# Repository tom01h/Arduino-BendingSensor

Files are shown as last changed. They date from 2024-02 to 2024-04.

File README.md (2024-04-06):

# ひずみゲージでスキー板のたわみを測る

[Arduino UNO R4もどきのボードと自作基板](https://github.com/tom01h/RA4M1)を使って実験します

事情あって、センサー部分は実際にスキー場で使っているものですが、制御部分はスキー場で使っているものとは別のものです

センサー部分は[ひずみゲージ](https://ja.aliexpress.com/item/1005003672107724.html)（BX120-100AA）と[HX711](https://ja.aliexpress.com/item/1005004245273524.html)（Mini Board）をちょい変(3.3V化)したものを使います

## Arduinoもどき

制御には[Arduino UNO R4もどきのボードと自作基板](https://github.com/tom01h/RA4M1)を使います

D5端子がクロック、D2,D3,D4端子がデータ入力端子です

プログラムは`BendingSensor.ino`です  
LCDに計測値を表示するためにu8g2ライブラリを使います

1秒に10回計測値を表示、最初の10回はゼロキャリブレーションに使います

### ピン配置
下の絵ではJ5,J9がDATA0(D4)で、絵には無いけどJ10,J11がDATA1(D3)でJ15,J16がDATA2(D2)です  
それぞれ、どちらか一方のコネクタを使います

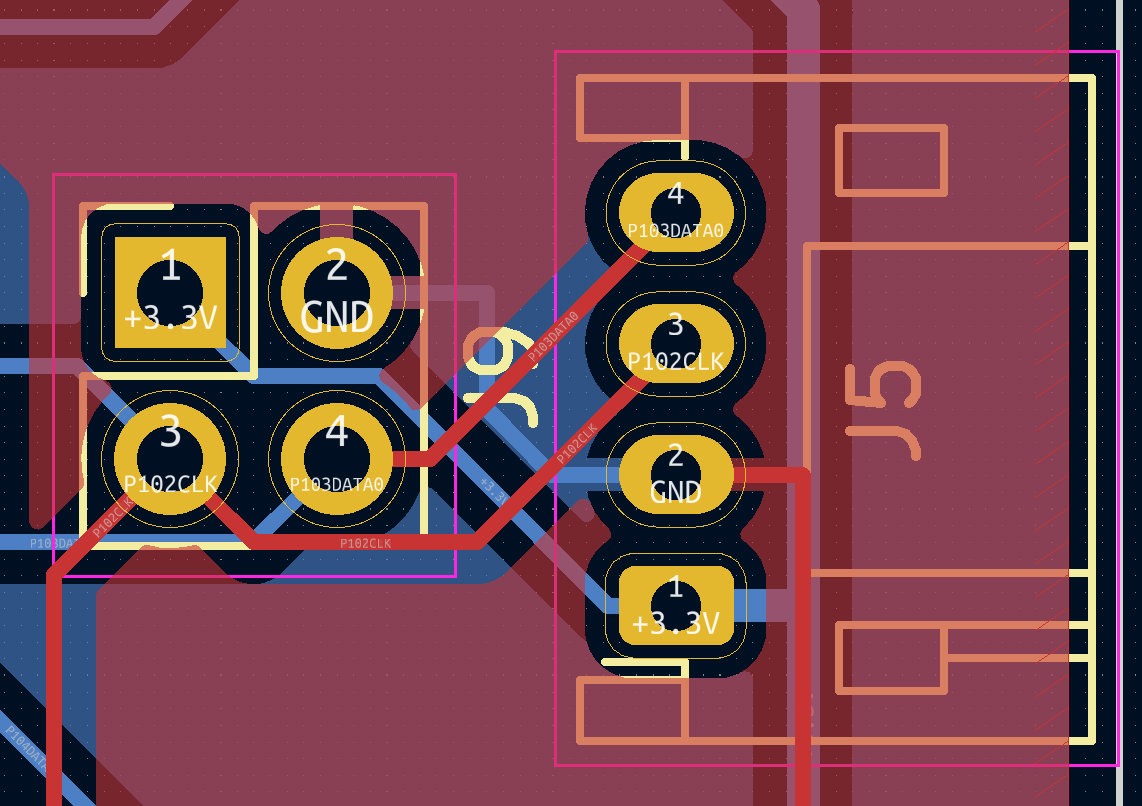
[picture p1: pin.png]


## センサー

### HX711を改造する
3.3Vに対応するために[ここ](https://kohacraft.com/archives/202103201133.html)の真似をして改造します  
(合成抵抗違うくね？って気はしますが…)  
とっても細かい作業です

2個のひずみゲージと組み合わせてホイートストンブリッジを作るための基板が`hx711.kicad_XX`です  
切り取って使います  
0.8mm厚で作りました  
あまり良くないと言われている基板同士のはんだ付け

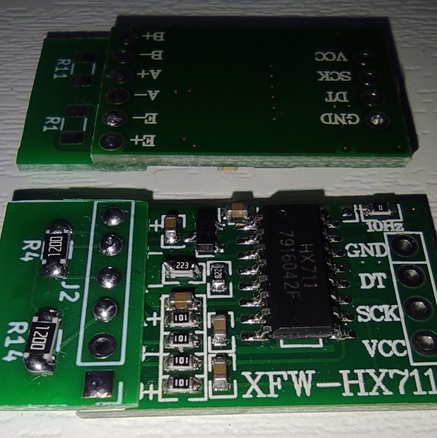
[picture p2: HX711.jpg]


### 回路
(E+)-(A+)間にひずみゲージを表向きに、(E+)-(A-)間にひずみゲージを裏向きに、(A+)-(E-)と(A-)-(E-)間は固定の抵抗(120Ω)をつなぎます  
2枚使っているのは温度補償のため  
スキー板の表裏に貼るわけにもいかないので、間に挟んだ0.4mm厚のプラバンに瞬間接着剤で固定しています  
それ以外の部分は大体でついていればよいので両面テープで固定しています

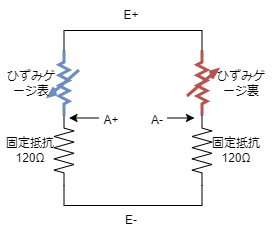
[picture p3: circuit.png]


### 設計図（のようなもの）
断面図

センサー部分は上から
- 100mm x 15mm のプラバン（0.4mm厚）
- 両面テープ
- ひずみゲージ（表）
- 瞬間接着剤
- 100mm x 15mm のプラバン（0.4mm厚）
- 瞬間接着剤
- ひずみゲージ（裏）
- 両面テープ
- 135mm x 15mm のプラバン（0.4mm厚）

HX711をプラバンに止めているのは1.2mm厚の両面テープ



センサー部分の平面図



### 組み立て
古い写真です
#### センサー部分

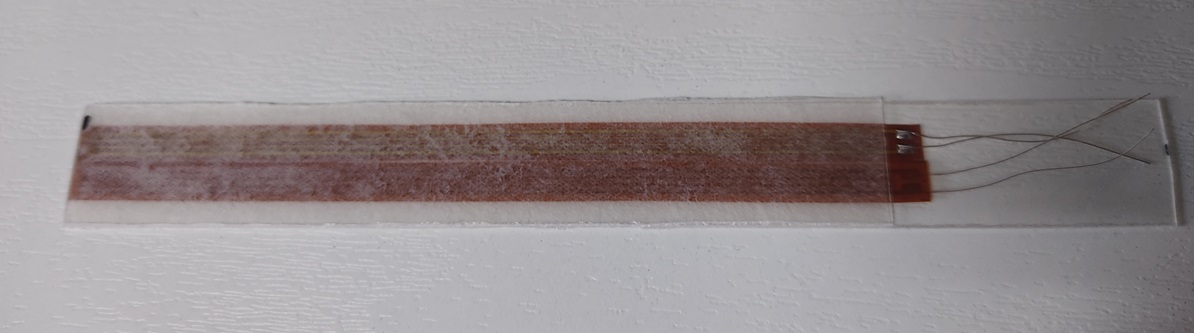
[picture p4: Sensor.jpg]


#### センサーとHX711接続
下の写真はHX711基板は裏返った状態

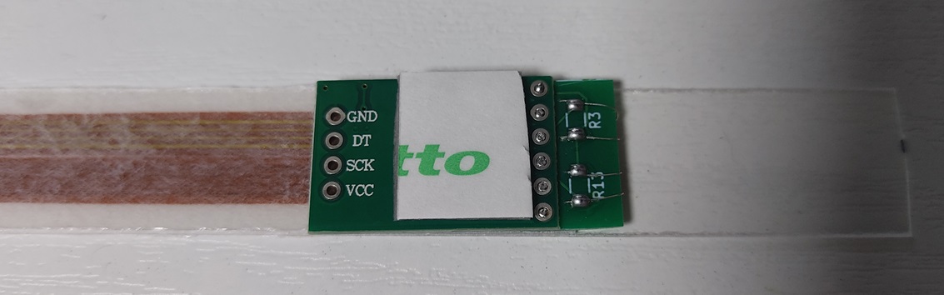
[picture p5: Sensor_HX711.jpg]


#### ケーブルの加工

4芯のケーブルは[これ](https://ja.aliexpress.com/item/4000570401041.html)の`AWG28 4Core`を使っているのだけど、ちょっと固すぎな気がします  
センサー（HX711）側は外皮（黒いの）2㎝だけむいて、中の線は5mmだけむいています  
外皮をむくのには[これ](https://ja.aliexpress.com/item/1005005504458064.html)を使っています  

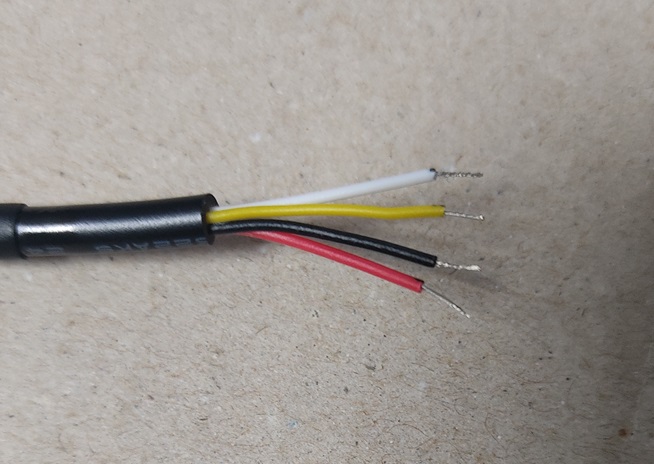
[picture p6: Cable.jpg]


制御基板側は長めに外皮（黒いの）をむいて、熱収縮チューブで保護しています  
コネクタは[これ](https://ja.aliexpress.com/item/1005003757087073.html)の4P  
Groveコネクタっぽい見た目ですが、電源とGNDを逆にするという致命的な間違いをしています。今更直せないのでこのままいきますが…  

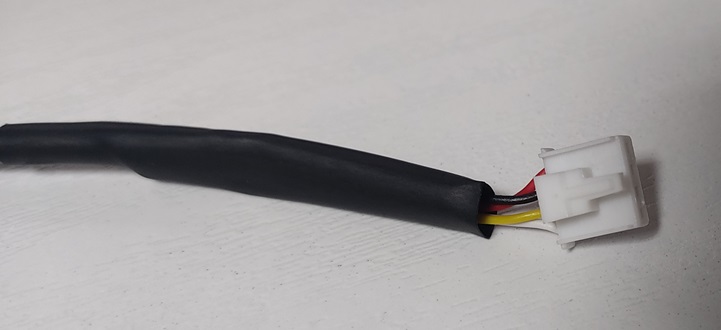
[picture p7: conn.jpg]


#### ケーブルに接続
1枚目が表から見た絵で2枚目が裏から見た絵

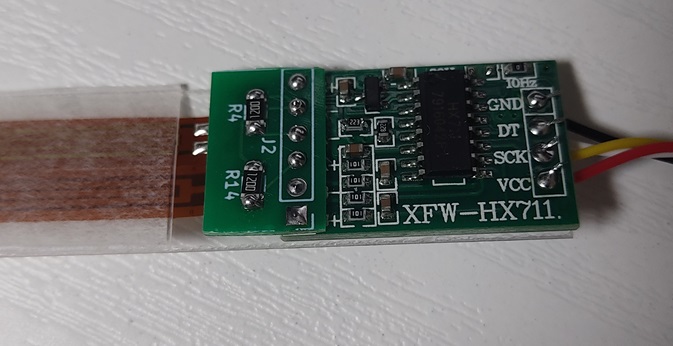
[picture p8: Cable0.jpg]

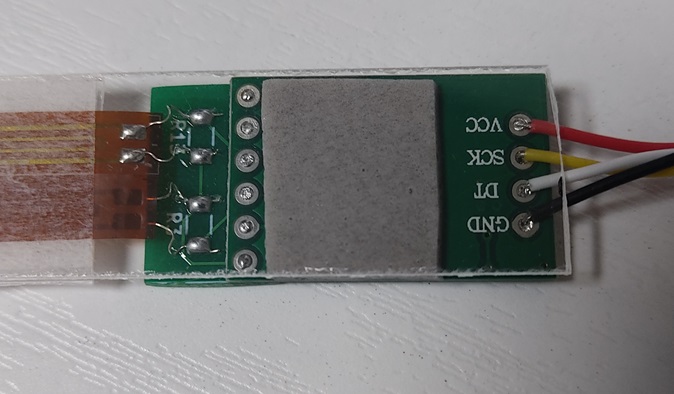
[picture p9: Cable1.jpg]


#### ホットボンド

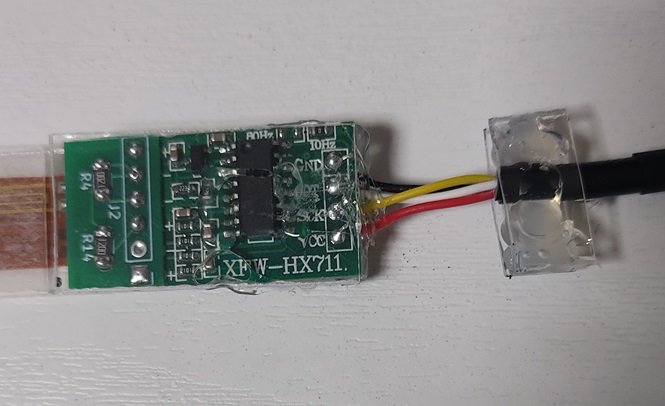
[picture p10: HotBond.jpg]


#### 熱収縮チューブ

長さ16㎝に切った直径12mmの[熱収縮チューブ](https://ja.aliexpress.com/item/32838965930.html)`12mm`を全体の保護に使います  
アイロンで加熱しますが、加熱しすぎに注意！！

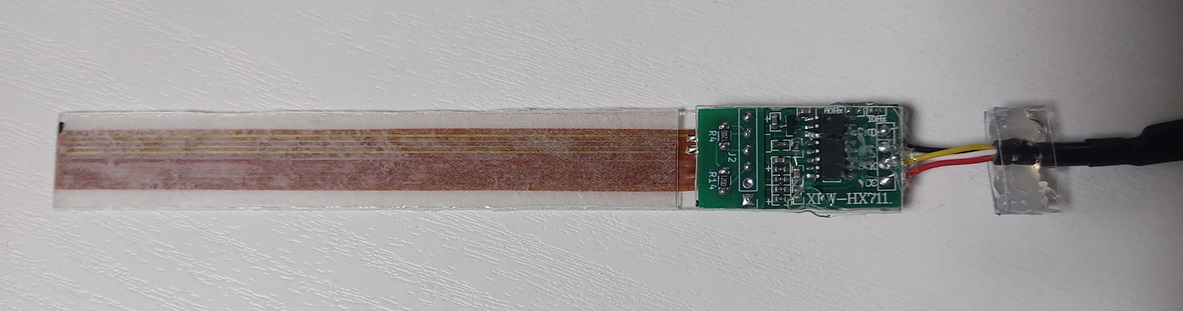
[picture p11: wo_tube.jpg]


↑をチューブでくるむと↓になる

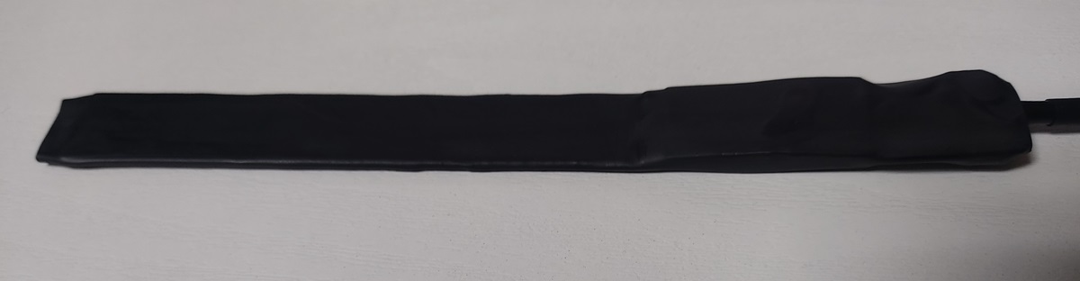
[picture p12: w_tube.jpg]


## 後処理

実際にスキー場で使うとノイズとドリフトがひどいのでバンドパスフィルターで後処理します  
後処理でドリフト消すなら温度補償いらなかったのでは？とも思いますが…

```
import numpy as np
from scipy import signal
from scipy import stats

略

    #バターワースフィルタ（バンドパス）
    def bandpass(x, samplerate, fp, fs, gpass, gstop):
        fn = samplerate / 2                               #ナイキスト周波数
        wp = fp / fn                                      #ナイキスト周波数で通過域端周波数を正規化
        ws = fs / fn                                      #ナイキスト周波数で阻止域端周波数を正規化
        N, Wn = signal.buttord(wp, ws, gpass, gstop)      #オーダーとバターワースの正規化周波数を計算
        b, a = signal.butter(N, Wn, "band")               #フィルタ伝達関数の分子と分母を計算
        y = signal.filtfilt(b, a, x)                      #信号に対してフィルタをかける
        return y

略

    samplerate = 10
    gpass = 3    #通過域端最大損失[dB]
    gstop = 40   #阻止域端最小損失[dB]

    # バンドパス
    fp = np.array([0.06, 2])   # 通過域端周波数[Hz]
    fs = np.array([0.03, 4])   # 阻止域端周波数[Hz]
    for i in range(6):
        x=y[i]
        y[i] = bandpass(x, samplerate, fp, fs, gpass, gstop)

    # 正規化
    for i in range(6):
        x=y[i]
        y[i] = stats.zscore(x)
```

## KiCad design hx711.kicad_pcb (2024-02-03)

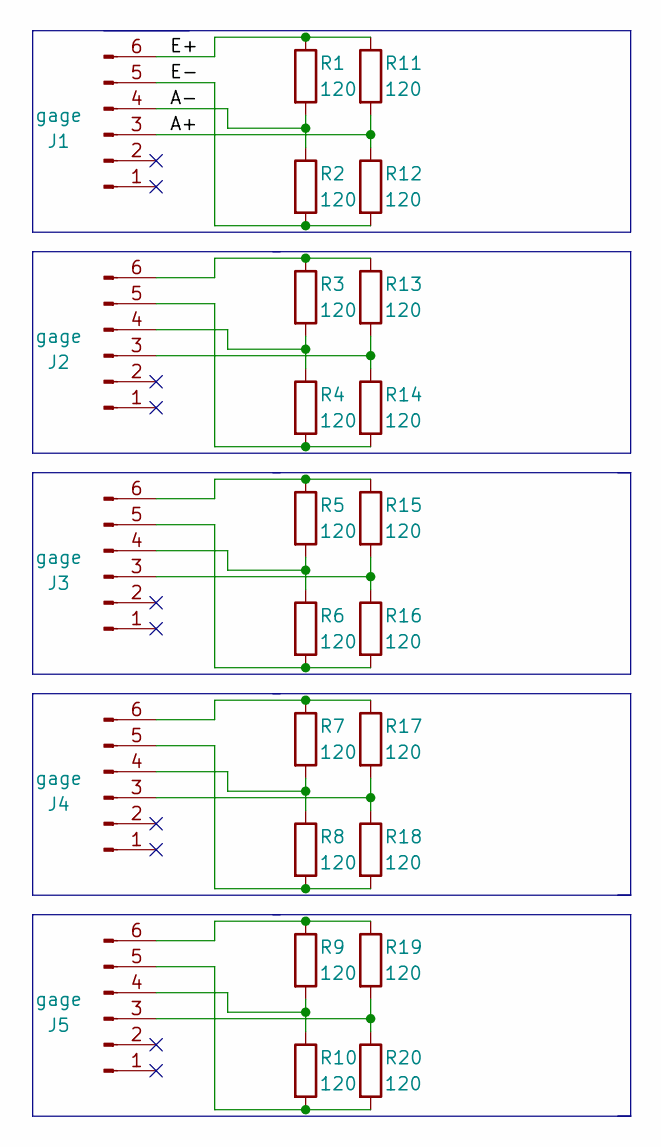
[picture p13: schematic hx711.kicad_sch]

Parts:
J1, J2, J3, J4, J5: gage; PinHeader_1x06_P2.54mm_Vertical
R1, R2, R3, R4, R5, R6, R7, R8, R9, R10, R11, R12, R13, R14, R15, R16, R17, R18, R19, R20: 120; R_1206_3216Metric_Pad1.30x1.75mm_HandSolder

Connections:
/A+: J1.3, R11.2, R12.1
/A-: J1.4, R1.2, R2.1
/E+: J1.6, R1.1, R11.1
/E-: J1.5, R2.2, R12.2
unnamed: J2.3, R13.2, R14.1
unnamed: J2.4, R3.2, R4.1
unnamed: J2.5, R4.2, R14.2
unnamed: J2.6, R3.1, R13.1
unnamed: J3.3, R15.2, R16.1
unnamed: J3.4, R5.2, R6.1
unnamed: J3.5, R6.2, R16.2
unnamed: J3.6, R5.1, R15.1
unnamed: J4.3, R17.2, R18.1
unnamed: J4.4, R7.2, R8.1
unnamed: J4.5, R8.2, R18.2
unnamed: J4.6, R7.1, R17.1
unnamed: J5.3, R19.2, R20.1
unnamed: J5.4, R9.2, R10.1
unnamed: J5.5, R10.2, R20.2
unnamed: J5.6, R9.1, R19.1

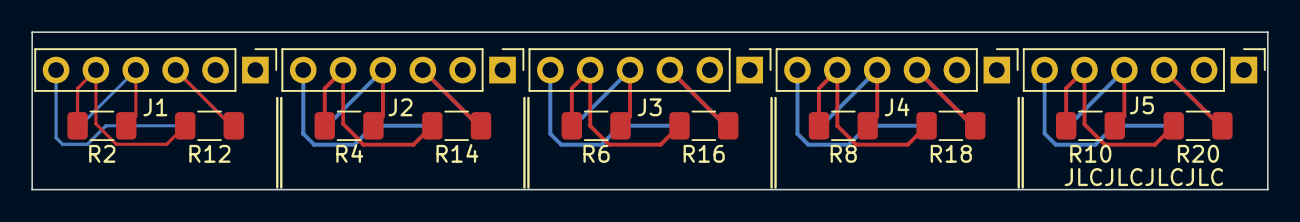
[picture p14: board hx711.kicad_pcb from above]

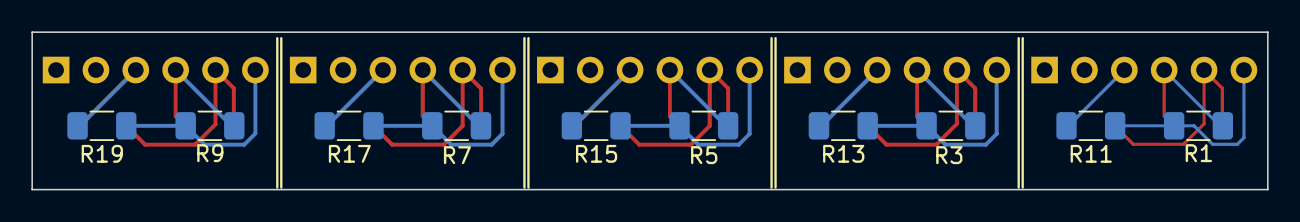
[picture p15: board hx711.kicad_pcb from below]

Board: 2 copper layers, 78.7 x 10.0 mm, 25 parts (10 on the bottom side), 20 nets.

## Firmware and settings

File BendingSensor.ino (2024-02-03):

#include <U8g2lib.h>

U8G2_SSD1306_128X32_UNIVISION_F_HW_I2C u8g2(U8G2_R2, /* reset=*/ U8X8_PIN_NONE);

int8_t zero_init = 10;

void setup() {
  // put your setup code here, to run once:
  Serial.begin(9600);

  pinMode(5, OUTPUT);
  pinMode(4, INPUT);
  pinMode(3, INPUT);
  pinMode(2, INPUT);

  u8g2.begin();
  u8g2.clearBuffer();
  u8g2.setFont(u8g2_font_6x10_tf);
  u8g2.drawStr(0,  7, "Hello world!");
  u8g2.drawStr(0, 17, "OLED screen TEST");
  u8g2.drawStr(0, 27, "with U8g2lib");
  u8g2.sendBuffer();

  zero_init = 10;
}

int bend_base[3] = {0};

void loop() {
  // Read HX711
  int atai[3] = {0};

  for (int i = 0; i < 24; i++) {
    digitalWrite(5, HIGH);
    __ASM volatile ("NOP");
    digitalWrite(5, LOW);
    __ASM volatile ("NOP");
    atai[0] = (atai[0] << 1) | (digitalRead(4));
    atai[1] = (atai[1] << 1) | (digitalRead(3));
    atai[2] = (atai[2] << 1) | (digitalRead(2));
  }
  digitalWrite(5, HIGH);
  __ASM volatile ("NOP");
  digitalWrite(5, LOW);
  __ASM volatile ("NOP");

  for(int i=0; i<3; i++){
    if(atai[i]>=(1<<23)){
      atai[i] -= (1<<24);
    }
  }

  if(zero_init>0){
    zero_init--;
    for(int i=0; i<3; i++){
      bend_base[i] += atai[i];
      if(zero_init==0){
        bend_base[i] /= 10;
      }
    }
    delay(100);
    return;
  }

  // put your main code here, to run repeatedly:
  Serial.println("hello world");
  Serial.println(atai[0]);
  Serial.println(atai[1]);
  Serial.println(atai[2]);
  
  for(int i=0; i<3; i++){
    atai[i] -= bend_base[i];
    atai[i] /= -100;
  }

  char s[10];
  u8g2.clearBuffer();
  itoa(atai[0],s,10);
  u8g2.drawStr(0,  7, s);
  itoa(atai[1],s,10);
  u8g2.drawStr(0, 17, s);
  itoa(atai[2],s,10);
  u8g2.drawStr(0, 27, s);
  u8g2.sendBuffer();
  
  delay(100);                      // wait for a second

}
